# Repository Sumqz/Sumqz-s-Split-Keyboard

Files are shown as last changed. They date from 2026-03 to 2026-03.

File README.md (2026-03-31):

# Sumqz-s-Split-Keyboard

## NOTE TO REVIEWER FROM BLUEPRINT: Because the projects exceeds the 100 dollar price limit of T3 projects i am willing to pay the additional 50 dollars needed. I am happy with a partial grant!

Hey everyone, this is my split keyboard project.

I always felt that traditional keyboards were functional but boring, so I decided to build my own. It can work as two separate halves or snap together with magnets to become a full 75% style keyboard in seconds.

It is hot-swappable, uses nRF52840 boards, and is designed to be easy to build at home.

I sanity-checked this design with my friend before finalizing it.

## Short Description

A DIY wireless split keyboard with magnetic attachment and hot-swap sockets.

## Pictures

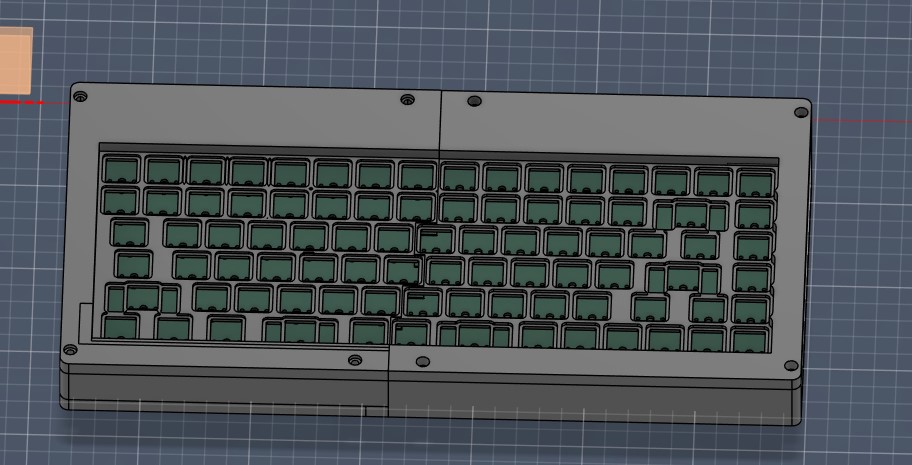
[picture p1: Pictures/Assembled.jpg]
Assembled

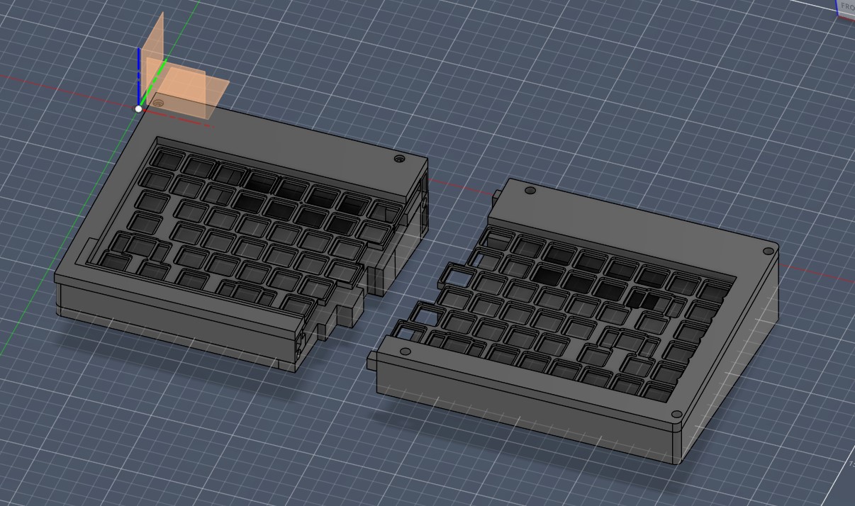
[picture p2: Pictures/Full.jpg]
Full

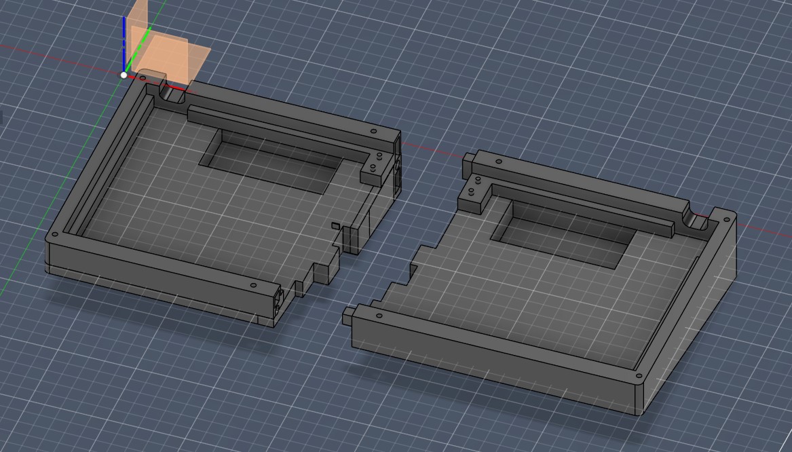
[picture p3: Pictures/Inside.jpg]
Inside

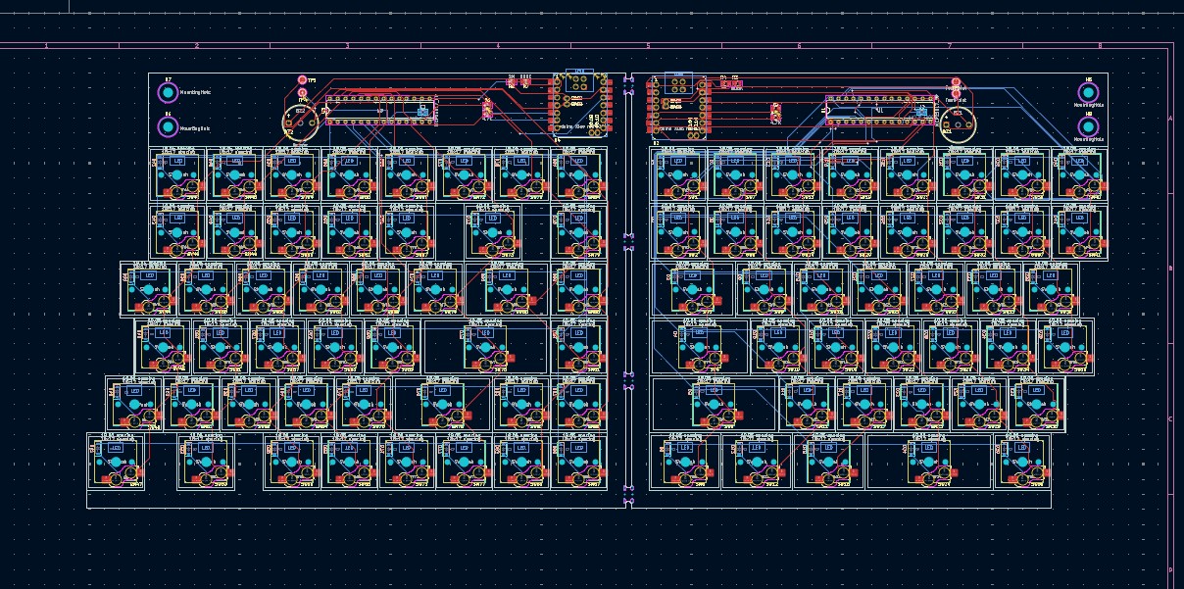
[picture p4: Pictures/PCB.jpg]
PCB

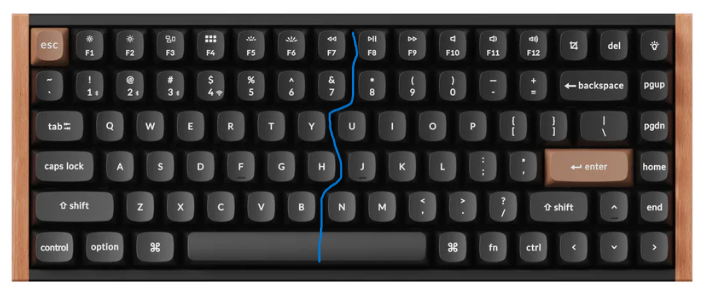
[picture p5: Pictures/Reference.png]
Reference

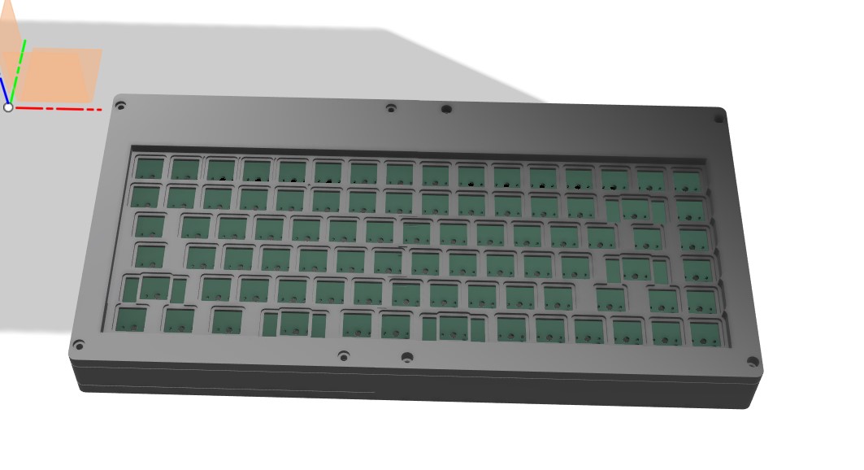
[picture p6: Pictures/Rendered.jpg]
Rendered

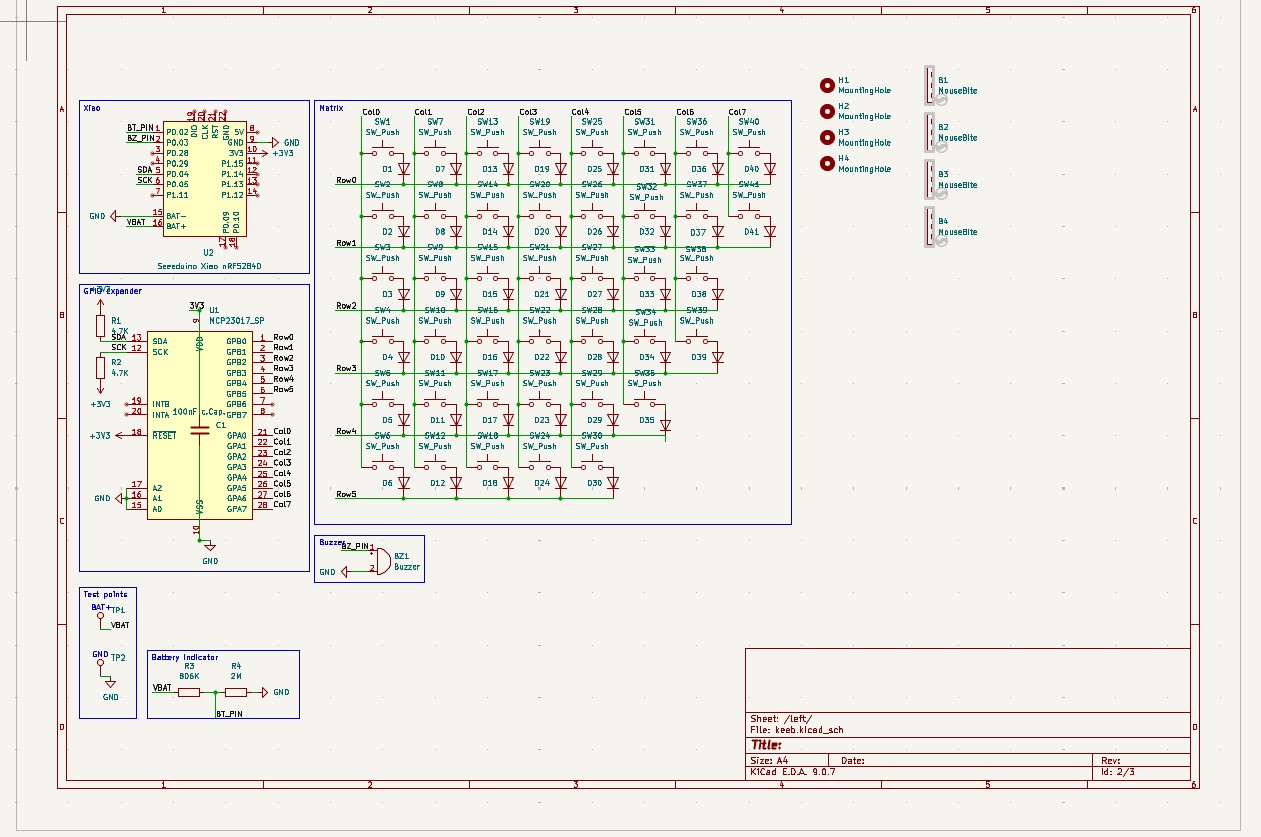
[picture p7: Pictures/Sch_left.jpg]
Schematic Left

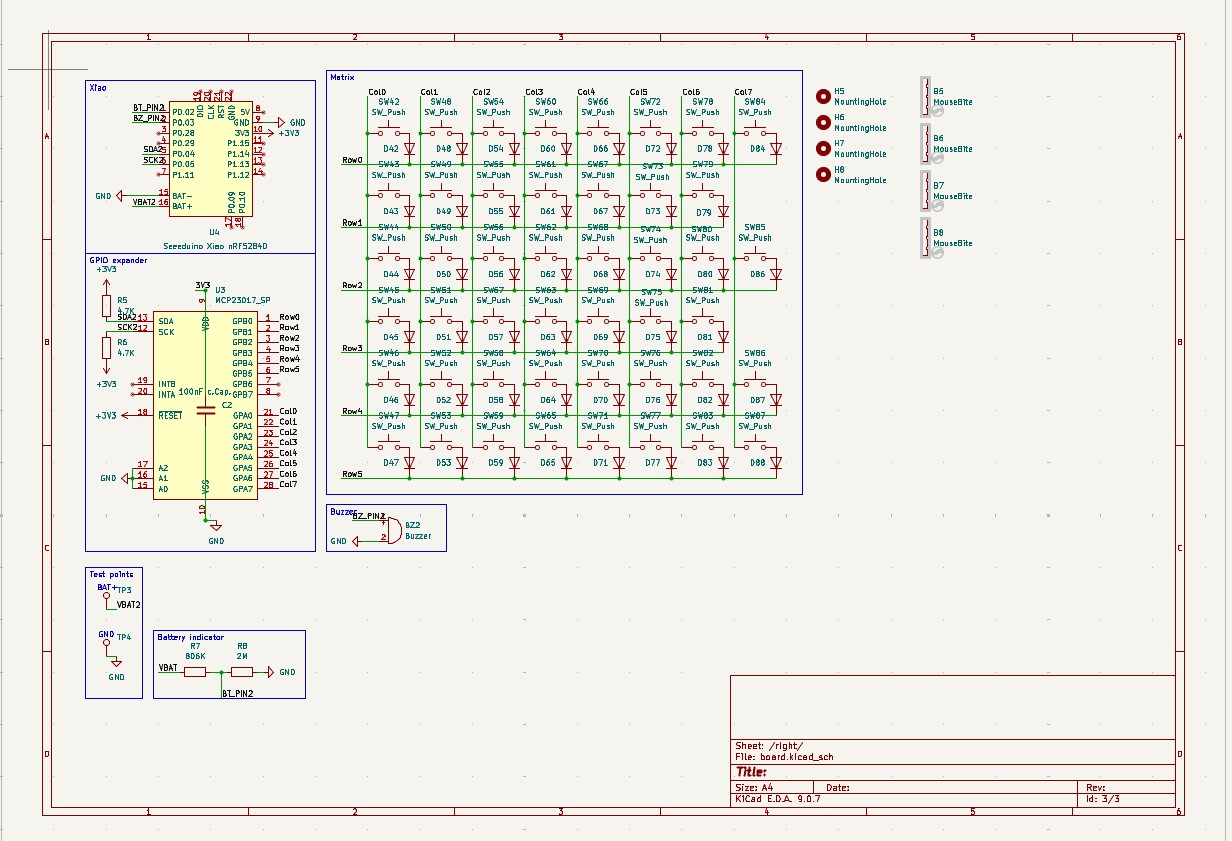
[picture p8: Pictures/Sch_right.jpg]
Schematic Right

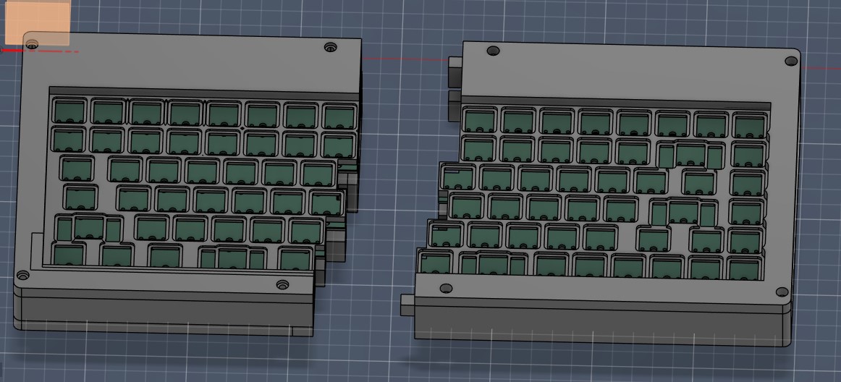
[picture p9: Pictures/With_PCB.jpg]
With PCB

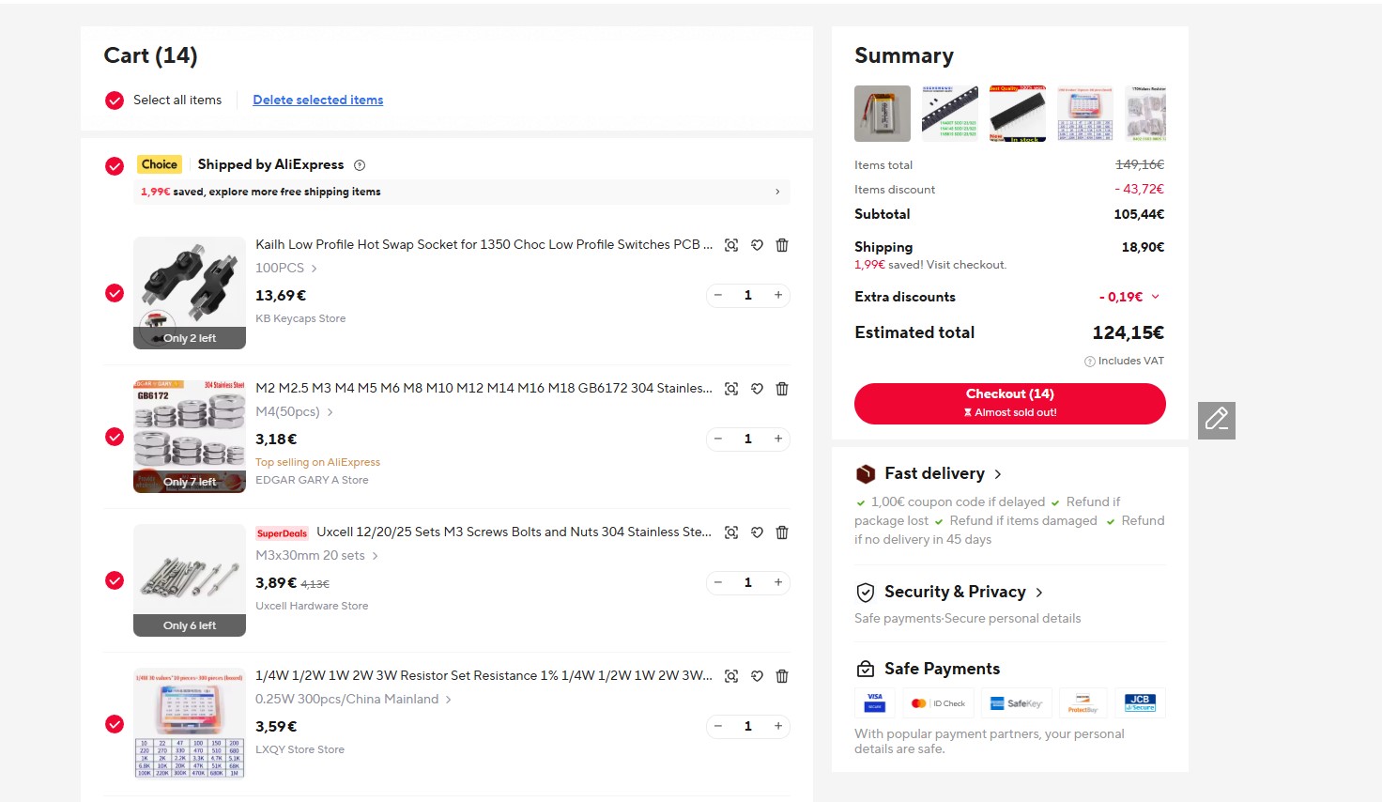
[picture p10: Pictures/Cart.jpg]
Cart

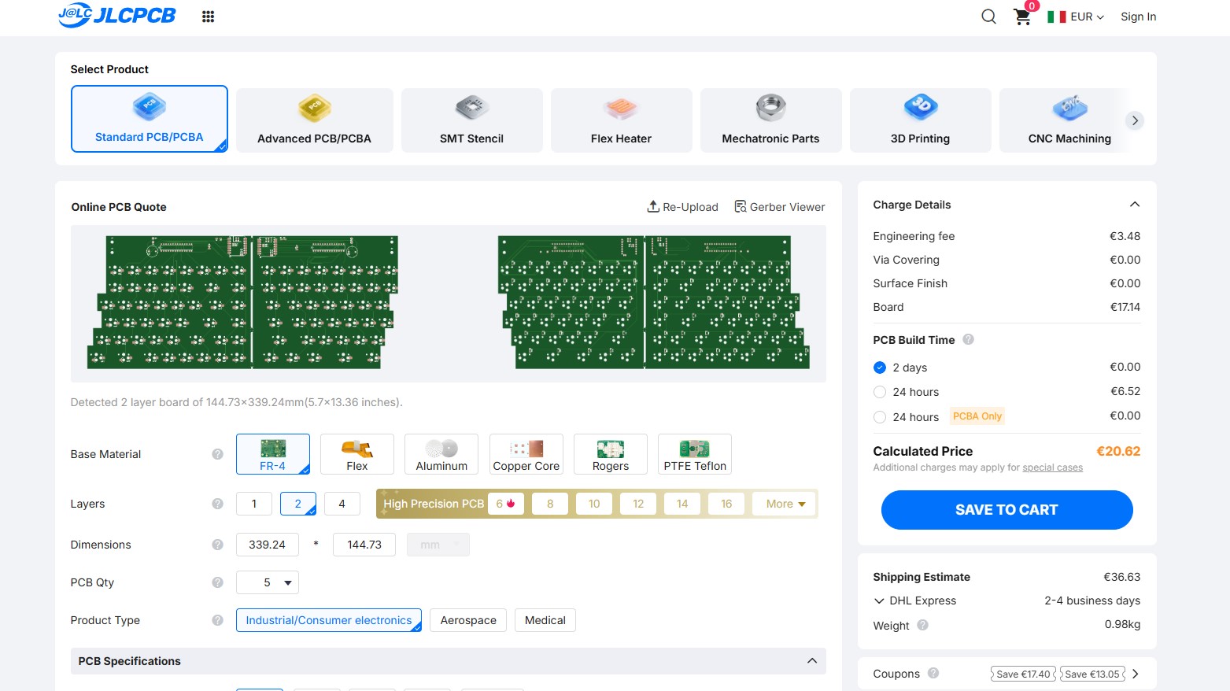
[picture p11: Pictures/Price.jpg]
Price


## Bill of Materials

| Part | Qty | Notes | Link |
|---|---:|---|---|
| nRF52840 (XIAO nRF52840) | 2 | One per side | [Buy](https://it.aliexpress.com/item/1005006988954136.html) |
| MCP23017 GPIO Expander | 2 | MCP23017_SP, DIP-28 package required | [Buy](https://it.aliexpress.com/item/1005009603989894.html) |
| LiPo 1200mAh | 2 | One per side | [Buy](https://it.aliexpress.com/item/1005011550469394.html) |
| Buzzer 12x9.5 / RM7.6 | 2 | Match PCB footprint pin spacing | [Buy](https://it.aliexpress.com/item/1005002576043967.html) |
| Switches (Holy Panda) | 87 | Total keys | [Buy](https://it.aliexpress.com/item/1005004388563696.html) |
| Keycaps (generic) | 87 | Match your layout | [Buy](https://it.aliexpress.com/item/1005011879391386.html) |
| Diodes 1N4148W (SOD-123) | 87 | One per switch | [Buy](https://it.aliexpress.com/item/1005003194674618.html) |
| Resistor 4.7k (0805) | 4 | R1, R2, R5, R6 | [Buy](https://it.aliexpress.com/item/1005011649990763.html) |
| Resistor 806k (0805) | 2 | R3, R7 | [Buy](https://it.aliexpress.com/item/1005011649990763.html) |
| Resistor 2M (0805) | 2 | R4, R8 | [Buy](https://it.aliexpress.com/item/1005011649990763.html) |
| Magnets 6x2 | 8 | 2 per hole | [Buy](https://it.aliexpress.com/item/1005009677185619.html) |
| M3 screw + nut | 4 | 40 mm | [Buy](https://it.aliexpress.com/item/1005008625463950.html) |
| M4 screw | 4 | 50 mm | [Buy](https://it.aliexpress.com/item/1005008625463950.html) |
| M4 nut | 4 | M4 | [Buy](https://it.aliexpress.com/item/1005010329406193.html) |
| Hotswap sockets | 87 | choc | [But](https://it.aliexpress.com/item/1005008543325730.html)

# Total price: about 150 euros or 167 dollars

PCB and case are not included because they are custom-made.

Resistor note: it is usually cheaper to buy one full 0805 resistor assortment than to buy each value separately.

## How to Use

Flash the `.ino` firmware to both nRF52840 boards. Then connect each half to your PC and test that every key works.

You can use it as a split keyboard, or snap both halves together with magnets to use it like a full 75% style board.

## Firmware

Firmware source: `Firmware/SplitKeyboard/SplitKeyboard.ino`

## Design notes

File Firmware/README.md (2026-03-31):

# SplitKeyboard Firmware

This firmware targets your netlist design:
- MCU: Seeed XIAO nRF52840
- Matrix expander: MCP23017 at `0x20`
- Matrix wiring: `GPA0..7 = Col0..7`, `GPB0..5 = Row0..5`
- Battery sense: `BT_PIN (P0.02 / A0)` with divider `806k/2M`

## Build UF2 (both halves)

From repository root:

```powershell
.\Firmware\build-uf2.ps1
```

Output UF2 files are copied to:
- `Production\UF2\SplitKeyboard-left.uf2`
- `Production\UF2\SplitKeyboard-right.uf2`

## Flash

1. Double-press reset on the XIAO board (UF2 drive appears).
2. Copy the matching UF2:
   - Left board: `SplitKeyboard-left.uf2`
   - Right board: `SplitKeyboard-right.uf2`

## Battery Percentage

Battery status is printed every 30 seconds on USB serial at `115200`:

```text
Battery: 84% (3.98V)
```

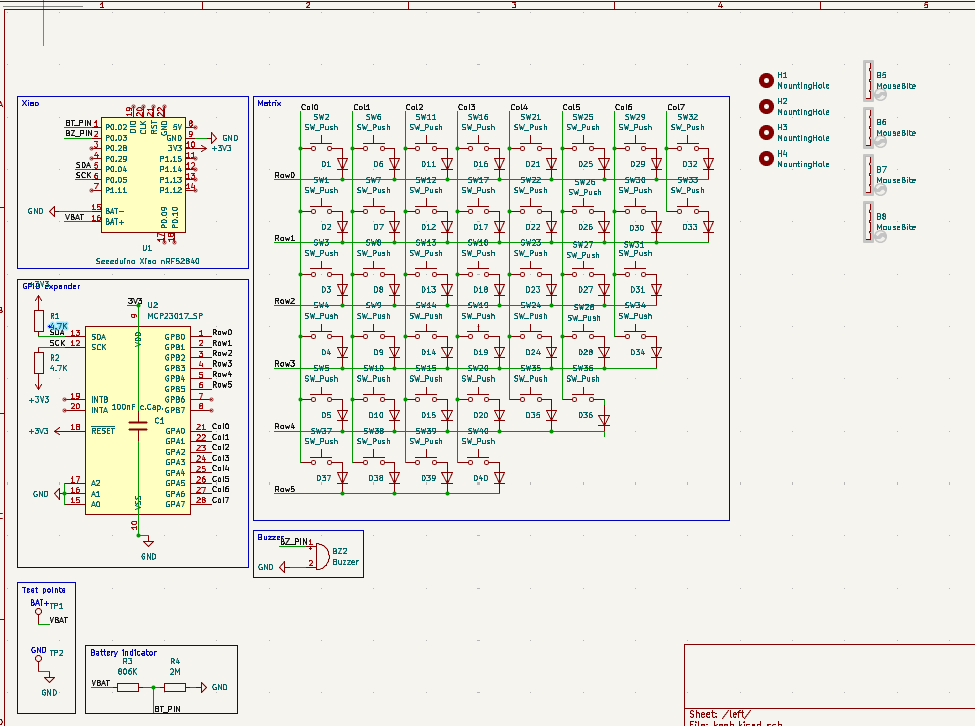
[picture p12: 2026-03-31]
PCB/SplitKeyboard/pics/sch_left.png

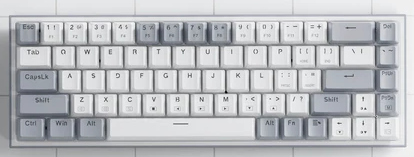
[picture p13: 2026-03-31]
PCB/SplitKeyboard/pics/Split_layout.png

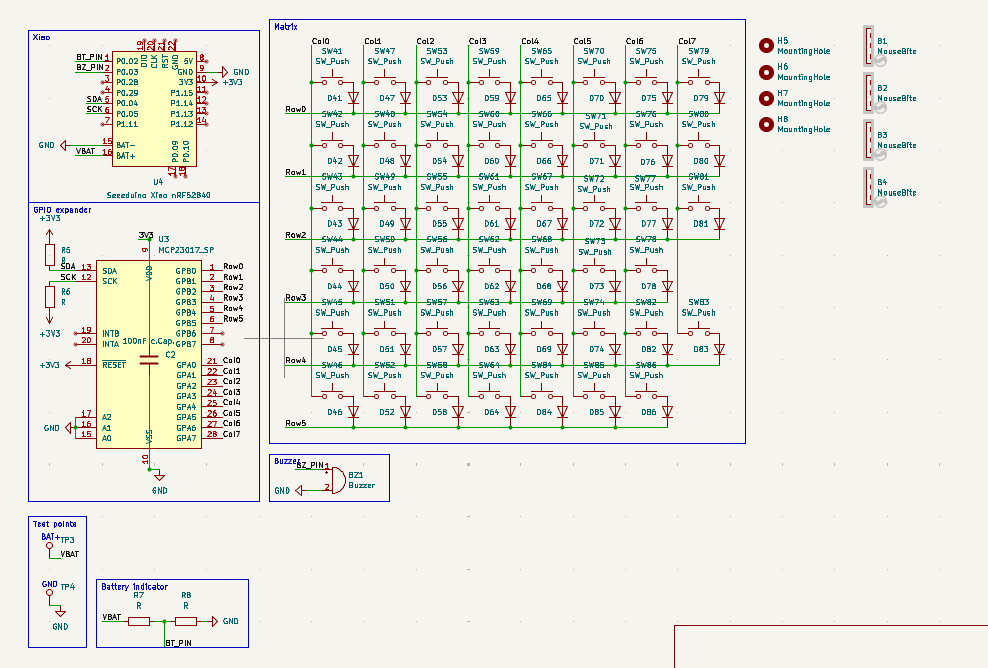
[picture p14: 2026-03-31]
PCB/SplitKeyboard/pics/sch_right.png

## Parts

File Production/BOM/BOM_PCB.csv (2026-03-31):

Id | Designator | Footprint | Quantity | Designation | Supplier and ref
1 | SW55,SW72,SW54,SW42,SW17,SW48,SW59,SW9,SW22,SW23,SW68,SW8,SW10,SW87,SW67,SW57,SW30,SW34,SW37,SW36,SW32,SW86,SW38,SW58,SW82,SW78,SW84,SW46,SW11,SW65,SW79,SW2,SW71,SW31,SW52,SW39,SW26,SW41,SW28,SW45,SW51,SW70,SW85,SW33,SW66,SW44,SW74,SW7,SW21,SW27,SW40,SW14,SW25,SW64,SW47,SW60,SW61,SW62,SW29,SW16,SW73,SW50,SW63,SW20,SW43,SW69,SW1,SW83,SW81,SW19,SW35,SW13,SW49,SW53,SW15,SW56,SW77 | SW_choc_v1_HS_CPG135001S30_1u | 77 | SW_Push
2 | R5,R6,R2,R1 | R_0805_2012Metric | 4 | 4.7K
3 | TP4,TP2,TP1,TP2,TP3 | TestPoint_Pad_D2.0mm | 5 | TestPoint
4 | U1,U3 | DIP-28_W7.62mm | 2 | MCP23017_SP
5 | BZ2,BZ1 | Buzzer_12x9.5RM7.6 | 2 | Buzzer
6 | SW4,SW76 | SW_choc_v1_HS_CPG135001S30_1.75u | 2 | SW_Push
7 | SW5,SW75,SW24 | SW_choc_v1_HS_CPG135001S30_2.25u | 3 | SW_Push
8 | R8,R4 | R_0805_2012Metric | 2 | 2M
9 | SW18,SW12,SW6 | SW_choc_v1_HS_CPG135001S30_1.25u | 3 | SW_Push
10 | SW80,SW3 | SW_choc_v1_HS_CPG135001S30_1.5u | 2 | SW_Push
11 | R7,R3 | R_0805_2012Metric | 2 | 806K
12 | D10,D44,D16,D22,D39,D38,D25,D5,D56,D46,D32,D49,D79,D71,D9,D6,D78,D55,D59,D8,D42,D68,D47,D18,D37,D36,D17,D4,D53,D64,D61,D88,D40,D60,D72,D27,D19,D45,D57,D12,D50,D58,D41,D2,D65,D67,D3,D48,D83,D24,D51,D74,D26,D81,D13,D69,D77,D23,D52,D15,D43,D75,D86,D66,D33,D1,D7,D84,D63,D31,D30,D11,D29,D87,D70,D20,D73,D21,D82,D34,D28,D76,D80,D62,D54,D35,D14 | D_SOD-123 | 87 | D
13 | C2,C1 | C_0805_2012Metric | 2 | 100nF c.Cap.

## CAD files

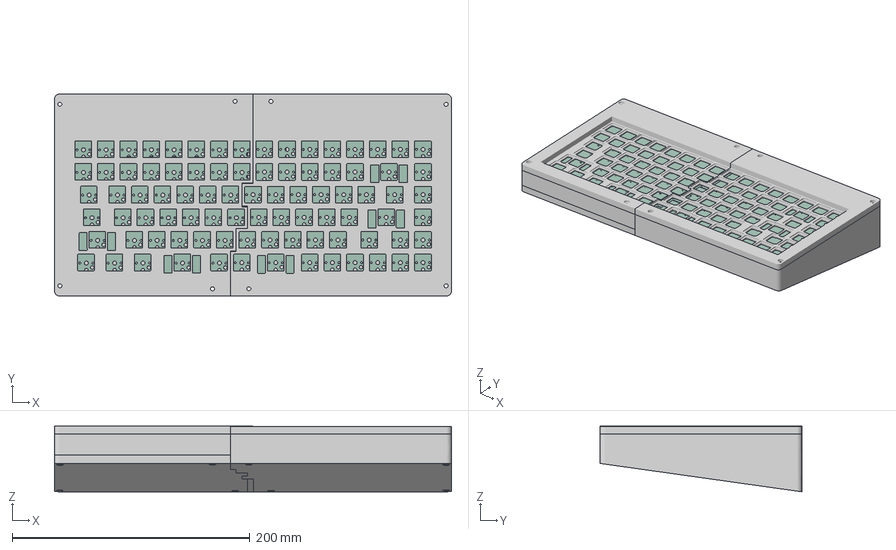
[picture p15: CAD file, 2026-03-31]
CAD/Split Keyboard.3mf
333.8 x 169.7 x 55.2 mm

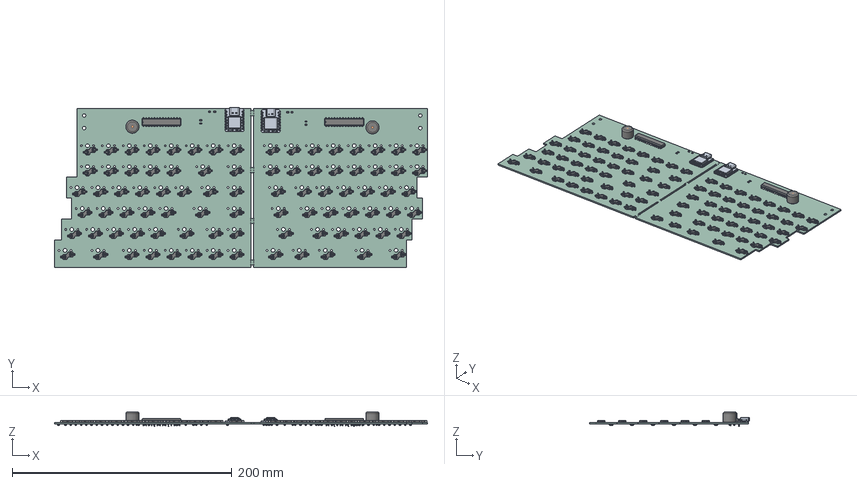
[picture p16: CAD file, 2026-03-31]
CAD/PCB.step
339.2 x 145.5 x 12.8 mm
pin x 174
socket x 87
R_0805_2012Metric x 8
DIP-28_W7.62mm x 2
Buzzer_12x9.5RM7.6 x 2
PCB 1.19.1 x 2
D_SOD-123 x 87
C_0805_2012Metric x 2
SplitKeyboard_PCB

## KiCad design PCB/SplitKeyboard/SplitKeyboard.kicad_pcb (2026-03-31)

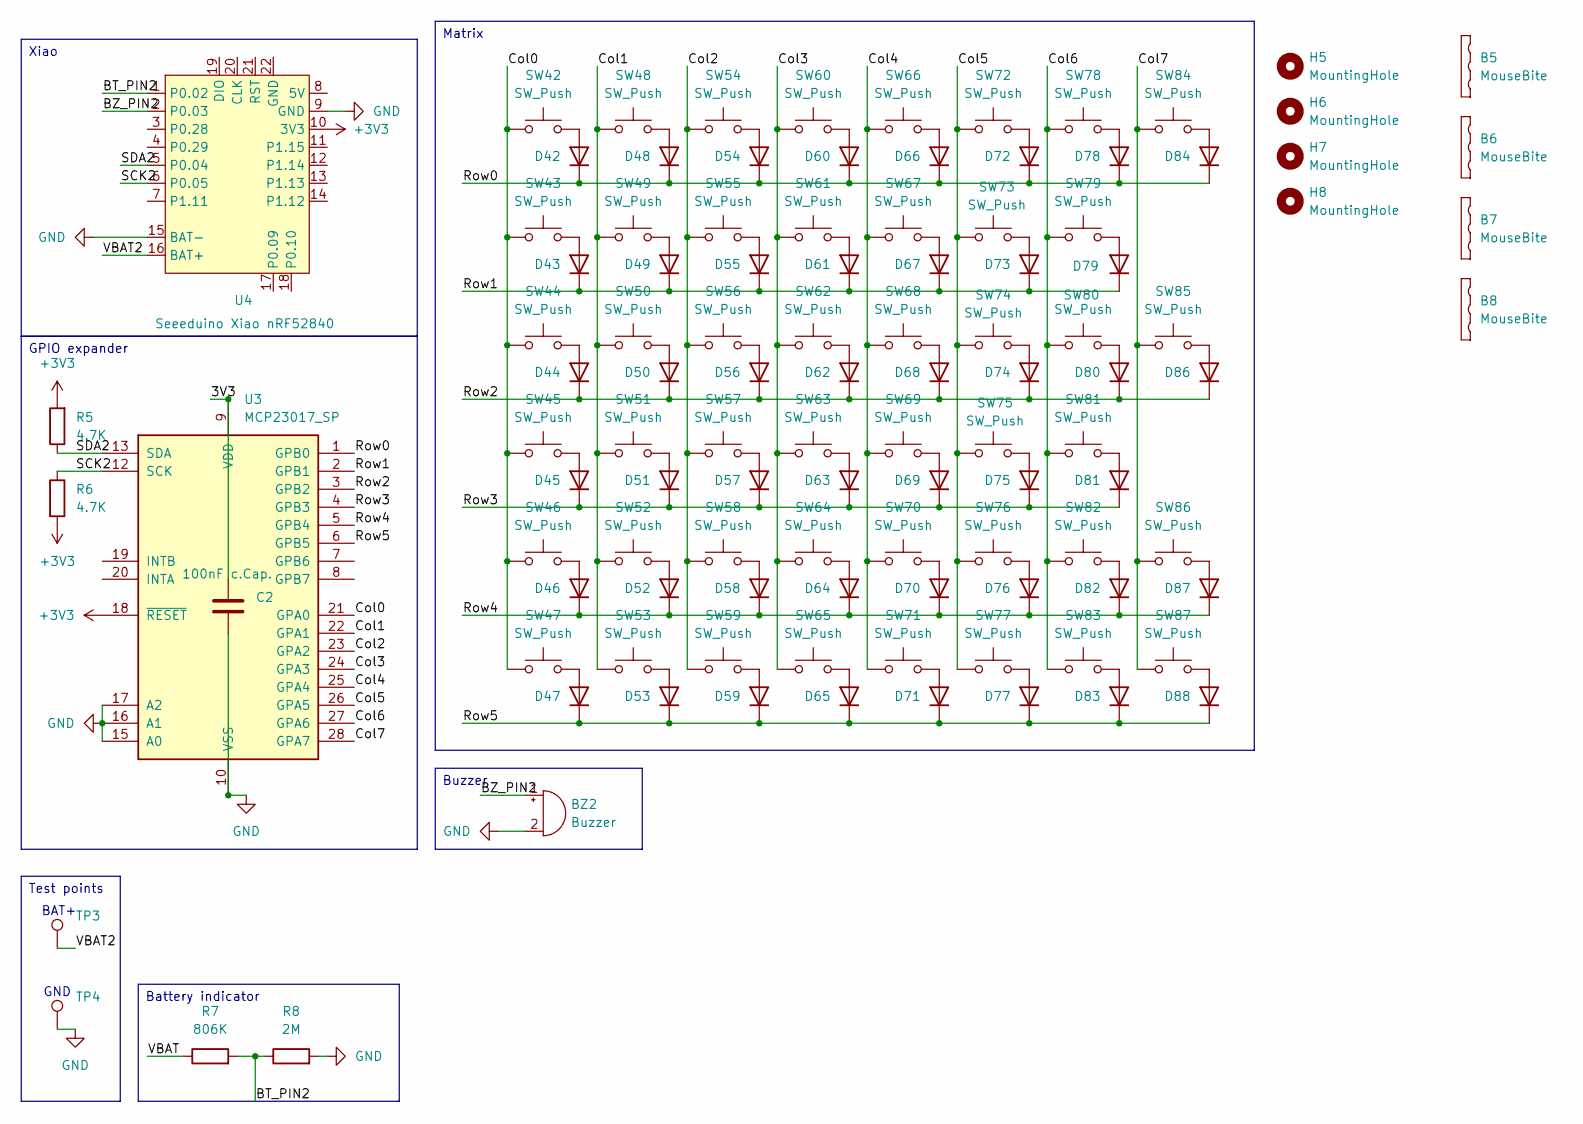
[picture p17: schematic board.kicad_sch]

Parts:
B5, B6, B7, B8: MouseBite; MouseBite-Slot_2.0x4.5mm_inset_D0.5mm_P0.85mm_5h_Trace
BZ2: Buzzer; Buzzer_12x9.5RM7.6
C2: 100nF c.Cap.; C_0805_2012Metric
D42, D43, D44, D45, D46, D47, D48, D49, D50, D51, D52, D53, D54, D55, D56, D57, D58, D59, D60, D61, D62, D63, D64, D65, D66, D67, D68, D69, D70, D71, D72, D73, D74, D75, D76, D77, D78, D79, D80, D81, D82, D83, D84, D86, D87, D88: D; D_SOD-123
H5, H6, H7, H8: MountingHole; MountingHole_3.2mm_M3
R5, R6: 4.7K; R_0805_2012Metric
R7: 806K; R_0805_2012Metric
R8: 2M; R_0805_2012Metric
SW42, SW43, SW44, SW45, SW46, SW47, SW48, SW49, SW50, SW51, SW52, SW53, SW54, SW55, SW56, SW57, SW58, SW59, SW60, SW61, SW62, SW63, SW64, SW65, SW66, SW67, SW68, SW69, SW70, SW71, SW72, SW73, SW74, SW77, SW78, SW79, SW81, SW82, SW83, SW84, SW85, SW86, SW87: SW_Push; SW_choc_v1_HS_CPG135001S30_1u
SW75: SW_Push; SW_choc_v1_HS_CPG135001S30_2.25u
SW76: SW_Push; SW_choc_v1_HS_CPG135001S30_1.75u
SW80: SW_Push; SW_choc_v1_HS_CPG135001S30_1.5u
TP3, TP4: TestPoint; TestPoint_Pad_D2.0mm
U3: MCP23017_SP; DIP-28_W7.62mm
U4: Seeeduino Xiao nRF52840; Xiao_nRF52840_ACH

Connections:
+3V3: R5.2, R6.2, U3.18 (~RESET), U4.10 (3V3); also elsewhere on the board
/right/3V3: C2.1, U3.9 (VDD)
/right/BT_PIN2: R7.2, R8.1, U4.1 (P0.02)
/right/BZ_PIN2: BZ2.1 (+), U4.2 (P0.03)
/right/Col0: SW42.1, SW43.1, SW44.1, SW45.1, SW46.1, SW47.1, U3.21 (GPA0)
/right/Col1: SW48.1, SW49.1, SW50.1, SW51.1, SW52.1, SW53.1, U3.22 (GPA1)
/right/Col2: SW54.1, SW55.1, SW56.1, SW57.1, SW58.1, SW59.1, U3.23 (GPA2)
/right/Col3: SW60.1, SW61.1, SW62.1, SW63.1, SW64.1, SW65.1, U3.24 (GPA3)
/right/Col4: SW66.1, SW67.1, SW68.1, SW69.1, SW70.1, SW71.1, U3.25 (GPA4)
/right/Col5: SW72.1, SW73.1, SW74.1, SW75.1, SW76.1, SW77.1, U3.26 (GPA5)
/right/Col6: SW78.1, SW79.1, SW80.1, SW81.1, SW82.1, SW83.1, U3.27 (GPA6)
/right/Col7: SW84.1, SW85.1, SW86.1, SW87.1, U3.28 (GPA7)
/right/Row0: D42.1 (K), D48.1 (K), D54.1 (K), D60.1 (K), D66.1 (K), D72.1 (K), D78.1 (K), D84.1 (K), U3.1 (GPB0)
/right/Row1: D43.1 (K), D49.1 (K), D55.1 (K), D61.1 (K), D67.1 (K), D73.1 (K), D79.1 (K), U3.2 (GPB1)
/right/Row2: D44.1 (K), D50.1 (K), D56.1 (K), D62.1 (K), D68.1 (K), D74.1 (K), D80.1 (K), D86.1 (K), U3.3 (GPB2)
/right/Row3: D45.1 (K), D51.1 (K), D57.1 (K), D63.1 (K), D69.1 (K), D75.1 (K), D81.1 (K), U3.4 (GPB3)
/right/Row4: D46.1 (K), D52.1 (K), D58.1 (K), D64.1 (K), D70.1 (K), D76.1 (K), D82.1 (K), D87.1 (K), U3.5 (GPB4)
/right/Row5: D47.1 (K), D53.1 (K), D59.1 (K), D65.1 (K), D71.1 (K), D77.1 (K), D83.1 (K), D88.1 (K), U3.6 (GPB5)
/right/SCK2: R6.1, U3.12 (SCK), U4.6 (P0.05)
/right/SDA2: R5.1, U3.13 (SDA), U4.5 (P0.04)
/right/VBAT: R7.1
/right/VBAT2: TP3.1, U4.16 (BAT+)
GND: BZ2.2 (-), C2.2, R8.2, TP4.1, U3.10 (VSS), U3.15 (A0), U3.16 (A1), U3.17 (A2), U4.9 (GND), U4.15 (BAT-); also elsewhere on the board
unnamed: D42.2 (A), SW42.2
unnamed: D43.2 (A), SW43.2
unnamed: D44.2 (A), SW44.2
unnamed: D45.2 (A), SW45.2
unnamed: D46.2 (A), SW46.2
unnamed: D47.2 (A), SW47.2
unnamed: D48.2 (A), SW48.2
unnamed: D49.2 (A), SW49.2
unnamed: D50.2 (A), SW50.2
unnamed: D51.2 (A), SW51.2
unnamed: D52.2 (A), SW52.2
unnamed: D53.2 (A), SW53.2
unnamed: D54.2 (A), SW54.2
unnamed: D55.2 (A), SW55.2
unnamed: D56.2 (A), SW56.2
unnamed: D57.2 (A), SW57.2
unnamed: D58.2 (A), SW58.2
unnamed: D59.2 (A), SW59.2
unnamed: D60.2 (A), SW60.2
unnamed: D61.2 (A), SW61.2
unnamed: D62.2 (A), SW62.2
unnamed: D63.2 (A), SW63.2
unnamed: D64.2 (A), SW64.2
unnamed: D65.2 (A), SW65.2
unnamed: D66.2 (A), SW66.2
unnamed: D67.2 (A), SW67.2
unnamed: D68.2 (A), SW68.2
unnamed: D69.2 (A), SW69.2
unnamed: D70.2 (A), SW70.2
unnamed: D71.2 (A), SW71.2
unnamed: D72.2 (A), SW72.2
unnamed: D73.2 (A), SW73.2
unnamed: D74.2 (A), SW74.2
unnamed: D75.2 (A), SW75.2
unnamed: D76.2 (A), SW76.2
unnamed: D77.2 (A), SW77.2
unnamed: D78.2 (A), SW78.2
unnamed: D79.2 (A), SW79.2
unnamed: D80.2 (A), SW80.2
unnamed: D81.2 (A), SW81.2
unnamed: D82.2 (A), SW82.2
unnamed: D83.2 (A), SW83.2
unnamed: D84.2 (A), SW84.2
unnamed: D86.2 (A), SW85.2
unnamed: D87.2 (A), SW86.2
unnamed: D88.2 (A), SW87.2

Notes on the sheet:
BAT+
GND
GPIO expander
Xiao
Test points
Buzzer
Battery indicator
Matrix

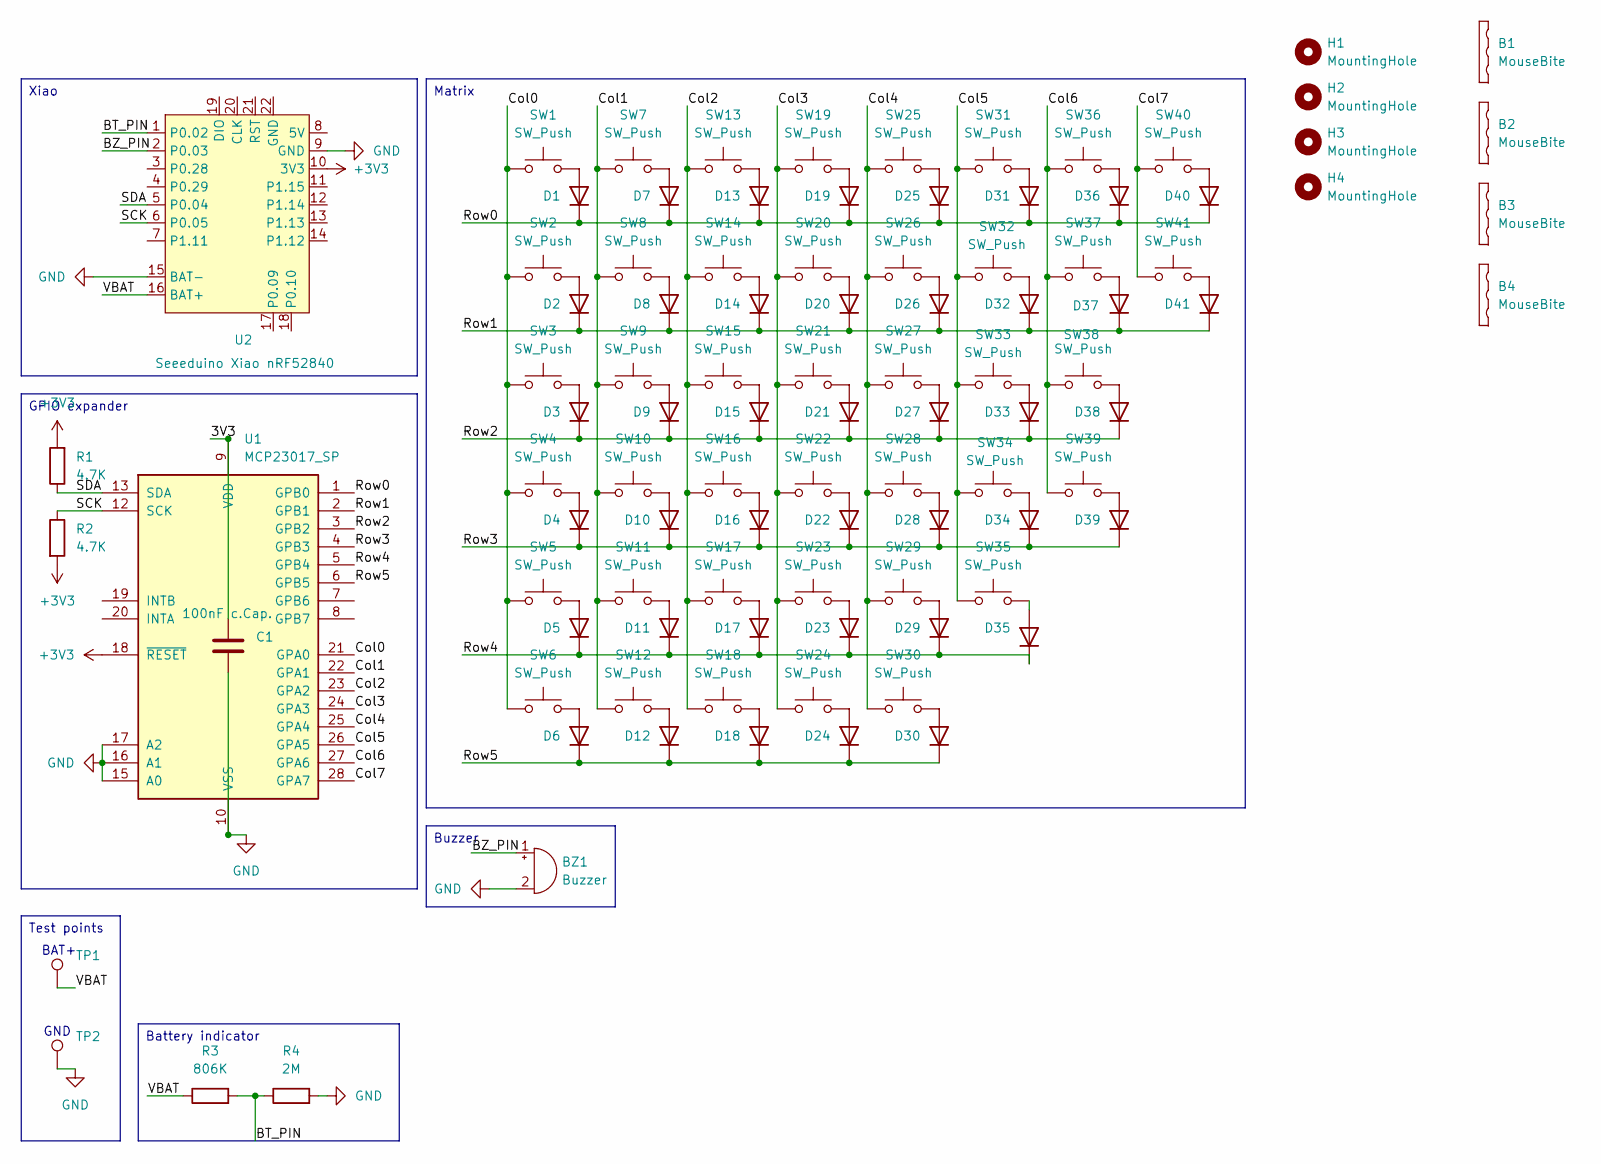
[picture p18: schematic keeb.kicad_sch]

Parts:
B1, B2, B3, B4: MouseBite; MouseBite-Slot_2.0x4.5mm_inset_D0.5mm_P0.85mm_5h_Trace
BZ1: Buzzer; Buzzer_12x9.5RM7.6
C1: 100nF c.Cap.; C_0805_2012Metric
D1, D2, D3, D4, D5, D6, D7, D8, D9, D10, D11, D12, D13, D14, D15, D16, D17, D18, D19, D20, D21, D22, D23, D24, D25, D26, D27, D28, D29, D30, D31, D32, D33, D34, D35, D36, D37, D38, D39, D40, D41: D; D_SOD-123
H1, H2, H3, H4: MountingHole; MountingHole_3.2mm_M3
R1, R2: 4.7K; R_0805_2012Metric
R3: 806K; R_0805_2012Metric
R4: 2M; R_0805_2012Metric
SW1, SW2, SW7, SW8, SW9, SW10, SW11, SW13, SW14, SW15, SW16, SW17, SW19, SW20, SW21, SW22, SW23, SW25, SW26, SW27, SW28, SW29, SW30, SW31, SW32, SW33, SW34, SW35, SW36, SW37, SW38, SW39, SW40, SW41: SW_Push; SW_choc_v1_HS_CPG135001S30_1u
SW3: SW_Push; SW_choc_v1_HS_CPG135001S30_1.5u
SW4: SW_Push; SW_choc_v1_HS_CPG135001S30_1.75u
SW5, SW24: SW_Push; SW_choc_v1_HS_CPG135001S30_2.25u
SW6, SW12, SW18: SW_Push; SW_choc_v1_HS_CPG135001S30_1.25u
TP1, TP2: TestPoint; TestPoint_Pad_D2.0mm
U1: MCP23017_SP; DIP-28_W7.62mm
U2: Seeeduino Xiao nRF52840; Xiao_nRF52840_ACH

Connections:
+3V3: R1.2, R2.2, U1.18 (~RESET), U2.10 (3V3); also elsewhere on the board
/left/3V3: C1.1, U1.9 (VDD)
/left/BT_PIN: R3.2, R4.1, U2.1 (P0.02)
/left/BZ_PIN: BZ1.1 (+), U2.2 (P0.03)
/left/Col0: SW1.1, SW2.1, SW3.1, SW4.1, SW5.1, SW6.1, U1.21 (GPA0)
/left/Col1: SW7.1, SW8.1, SW9.1, SW10.1, SW11.1, SW12.1, U1.22 (GPA1)
/left/Col2: SW13.1, SW14.1, SW15.1, SW16.1, SW17.1, SW18.1, U1.23 (GPA2)
/left/Col3: SW19.1, SW20.1, SW21.1, SW22.1, SW23.1, SW24.1, U1.24 (GPA3)
/left/Col4: SW25.1, SW26.1, SW27.1, SW28.1, SW29.1, SW30.1, U1.25 (GPA4)
/left/Col5: SW31.1, SW32.1, SW33.1, SW34.1, SW35.1, U1.26 (GPA5)
/left/Col6: SW36.1, SW37.1, SW38.1, SW39.1, U1.27 (GPA6)
/left/Col7: SW40.1, SW41.1, U1.28 (GPA7)
/left/Row0: D1.1 (K), D7.1 (K), D13.1 (K), D19.1 (K), D25.1 (K), D31.1 (K), D36.1 (K), D40.1 (K), U1.1 (GPB0)
/left/Row1: D2.1 (K), D8.1 (K), D14.1 (K), D20.1 (K), D26.1 (K), D32.1 (K), D37.1 (K), D41.1 (K), U1.2 (GPB1)
/left/Row2: D3.1 (K), D9.1 (K), D15.1 (K), D21.1 (K), D27.1 (K), D33.1 (K), D38.1 (K), U1.3 (GPB2)
/left/Row3: D4.1 (K), D10.1 (K), D16.1 (K), D22.1 (K), D28.1 (K), D34.1 (K), D39.1 (K), U1.4 (GPB3)
/left/Row4: D5.1 (K), D11.1 (K), D17.1 (K), D23.1 (K), D29.1 (K), D35.1 (K), U1.5 (GPB4)
/left/Row5: D6.1 (K), D12.1 (K), D18.1 (K), D24.1 (K), D30.1 (K), U1.6 (GPB5)
/left/SCK: R2.1, U1.12 (SCK), U2.6 (P0.05)
/left/SDA: R1.1, U1.13 (SDA), U2.5 (P0.04)
/left/VBAT: R3.1, TP1.1, U2.16 (BAT+)
GND: BZ1.2 (-), C1.2, R4.2, TP2.1, U1.10 (VSS), U1.15 (A0), U1.16 (A1), U1.17 (A2), U2.9 (GND), U2.15 (BAT-); also elsewhere on the board
unnamed: D1.2 (A), SW1.2
unnamed: D2.2 (A), SW2.2
unnamed: D3.2 (A), SW3.2
unnamed: D4.2 (A), SW4.2
unnamed: D5.2 (A), SW5.2
unnamed: D6.2 (A), SW6.2
unnamed: D7.2 (A), SW7.2
unnamed: D8.2 (A), SW8.2
unnamed: D9.2 (A), SW9.2
unnamed: D10.2 (A), SW10.2
unnamed: D11.2 (A), SW11.2
unnamed: D12.2 (A), SW12.2
unnamed: D13.2 (A), SW13.2
unnamed: D14.2 (A), SW14.2
unnamed: D15.2 (A), SW15.2
unnamed: D16.2 (A), SW16.2
unnamed: D17.2 (A), SW17.2
unnamed: D18.2 (A), SW18.2
unnamed: D19.2 (A), SW19.2
unnamed: D20.2 (A), SW20.2
unnamed: D21.2 (A), SW21.2
unnamed: D22.2 (A), SW22.2
unnamed: D23.2 (A), SW23.2
unnamed: D24.2 (A), SW24.2
unnamed: D25.2 (A), SW25.2
unnamed: D26.2 (A), SW26.2
unnamed: D27.2 (A), SW27.2
unnamed: D28.2 (A), SW28.2
unnamed: D29.2 (A), SW29.2
unnamed: D30.2 (A), SW30.2
unnamed: D31.2 (A), SW31.2
unnamed: D32.2 (A), SW32.2
unnamed: D33.2 (A), SW33.2
unnamed: D34.2 (A), SW34.2
unnamed: D35.2 (A), SW35.2
unnamed: D36.2 (A), SW36.2
unnamed: D37.2 (A), SW37.2
unnamed: D38.2 (A), SW38.2
unnamed: D39.2 (A), SW39.2
unnamed: D40.2 (A), SW40.2
unnamed: D41.2 (A), SW41.2

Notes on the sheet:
GND
BAT+
Battery indicator
Buzzer
Matrix
GPIO expander
Xiao
Test points

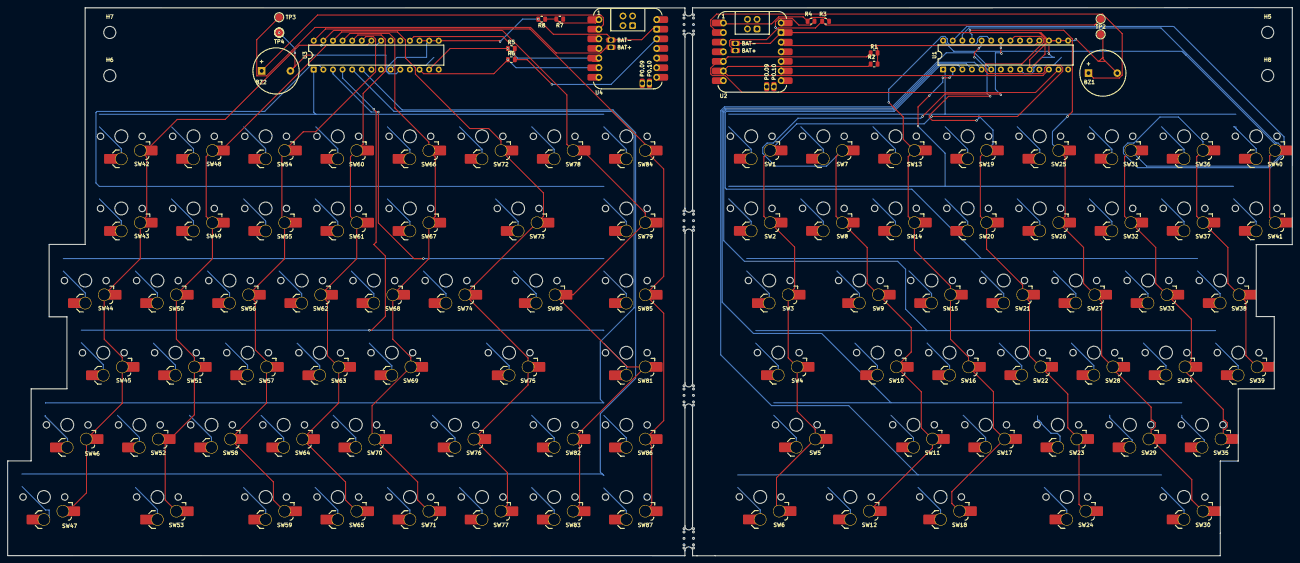
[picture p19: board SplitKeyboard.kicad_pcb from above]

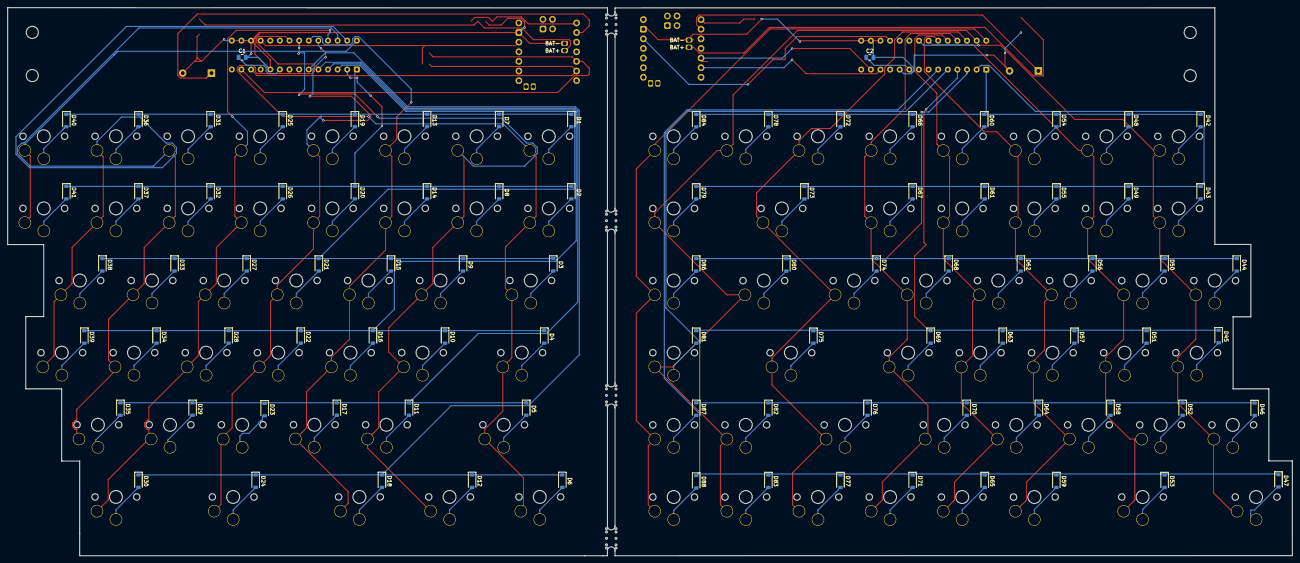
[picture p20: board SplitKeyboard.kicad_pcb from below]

Board: 2 copper layers, 339.2 x 144.7 mm, 203 parts (89 on the bottom side), 129 nets.

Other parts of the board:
TP2#2: TestPoint; TestPoint_Pad_D2.0mm

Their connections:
GND: TP2#2.1; also elsewhere on the board

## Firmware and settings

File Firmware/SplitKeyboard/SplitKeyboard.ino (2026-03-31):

#include <Arduino.h>
#include <Wire.h>
#include <Adafruit_MCP23X17.h>
#include <PluggableUSBHID.h>
#include <USBKeyboard.h>

#if !defined(HALF_LEFT) && !defined(HALF_RIGHT)
#define HALF_LEFT
#endif

namespace {
constexpr uint8_t kRows = 6;
constexpr uint8_t kCols = 8;
constexpr uint8_t kMcpAddress = 0x20;
constexpr uint8_t kDebounceMs = 5;

constexpr uint8_t kBatterySensePin = A0;
constexpr uint8_t kBuzzerPin = D1;

constexpr float kBatteryDividerScale = (806.0f + 2000.0f) / 2000.0f;
constexpr float kBatteryEmptyV = 3.30f;
constexpr float kBatteryFullV = 4.20f;

constexpr uint8_t H_A = 0x04;
constexpr uint8_t H_B = 0x05;
constexpr uint8_t H_C = 0x06;
constexpr uint8_t H_D = 0x07;
constexpr uint8_t H_E = 0x08;
constexpr uint8_t H_F = 0x09;
constexpr uint8_t H_G = 0x0A;
constexpr uint8_t H_H = 0x0B;
constexpr uint8_t H_I = 0x0C;
constexpr uint8_t H_J = 0x0D;
constexpr uint8_t H_K = 0x0E;
constexpr uint8_t H_L = 0x0F;
constexpr uint8_t H_M = 0x10;
constexpr uint8_t H_N = 0x11;
constexpr uint8_t H_O = 0x12;
constexpr uint8_t H_P = 0x13;
constexpr uint8_t H_Q = 0x14;
constexpr uint8_t H_R = 0x15;
constexpr uint8_t H_S = 0x16;
constexpr uint8_t H_T = 0x17;
constexpr uint8_t H_U = 0x18;
constexpr uint8_t H_V = 0x19;
constexpr uint8_t H_W = 0x1A;
constexpr uint8_t H_X = 0x1B;
constexpr uint8_t H_Y = 0x1C;
constexpr uint8_t H_Z = 0x1D;
constexpr uint8_t H_1 = 0x1E;
constexpr uint8_t H_2 = 0x1F;
constexpr uint8_t H_3 = 0x20;
constexpr uint8_t H_4 = 0x21;
constexpr uint8_t H_5 = 0x22;
constexpr uint8_t H_6 = 0x23;
constexpr uint8_t H_7 = 0x24;
constexpr uint8_t H_8 = 0x25;
constexpr uint8_t H_9 = 0x26;
constexpr uint8_t H_0 = 0x27;
constexpr uint8_t H_ENTER = 0x28;
constexpr uint8_t H_ESC = 0x29;
constexpr uint8_t H_BKSP = 0x2A;
constexpr uint8_t H_TAB = 0x2B;
constexpr uint8_t H_SPACE = 0x2C;
constexpr uint8_t H_MINUS = 0x2D;
constexpr uint8_t H_EQUAL = 0x2E;
constexpr uint8_t H_LBKT = 0x2F;
constexpr uint8_t H_RBKT = 0x30;
constexpr uint8_t H_BSLS = 0x31;
constexpr uint8_t H_SCLN = 0x33;
constexpr uint8_t H_QUOT = 0x34;
constexpr uint8_t H_COMM = 0x36;
constexpr uint8_t H_DOT = 0x37;
constexpr uint8_t H_SLSH = 0x38;
constexpr uint8_t H_CAPS = 0x39;
constexpr uint8_t H_F7 = 0x40;
constexpr uint8_t H_F8 = 0x41;
constexpr uint8_t H_F9 = 0x42;
constexpr uint8_t H_F10 = 0x43;
constexpr uint8_t H_F11 = 0x44;
constexpr uint8_t H_F12 = 0x45;
constexpr uint8_t H_INS = 0x49;
constexpr uint8_t H_HOME = 0x4A;
constexpr uint8_t H_PGUP = 0x4B;
constexpr uint8_t H_DEL = 0x4C;
constexpr uint8_t H_END = 0x4D;
constexpr uint8_t H_PGDN = 0x4E;
constexpr uint8_t H_RIGHT = 0x4F;
constexpr uint8_t H_LEFT = 0x50;
constexpr uint8_t H_DOWN = 0x51;
constexpr uint8_t H_UP = 0x52;

struct KeyDef {
  uint8_t usage;
  uint8_t modifier;
};

constexpr KeyDef N = {0, 0};
constexpr KeyDef K(uint8_t usage) { return {usage, 0}; }
constexpr KeyDef M(uint8_t modifier) { return {0, modifier}; }

constexpr uint8_t kColPins[kCols] = {0, 1, 2, 3, 4, 5, 6, 7};
constexpr uint8_t kRowPins[kRows] = {8, 9, 10, 11, 12, 13};

const KeyDef kLeftKeymap[kRows][kCols] = {
  {K(H_ESC), K(H_1), K(H_2), K(H_3), K(H_4), K(H_5), K(H_6), K(H_7)},
  {K(H_TAB), K(H_Q), K(H_W), K(H_E), K(H_R), K(H_T), K(H_Y), K(H_U)},
  {K(H_CAPS), K(H_A), K(H_S), K(H_D), K(H_F), K(H_G), K(H_H), N},
  {M(arduino::KEY_SHIFT), K(H_Z), K(H_X), K(H_C), K(H_V), K(H_B), K(H_N), N},
  {M(arduino::KEY_CTRL), M(arduino::KEY_LOGO), M(arduino::KEY_ALT), K(H_SPACE), K(H_BKSP), K(H_ENTER), N, N},
  {K(H_LEFT), K(H_DOWN), K(H_UP), K(H_RIGHT), K(H_DEL), N, N, N}
};

const KeyDef kRightKeymap[kRows][kCols] = {
  {K(H_8), K(H_9), K(H_0), K(H_MINUS), K(H_EQUAL), K(H_LBKT), K(H_RBKT), K(H_BSLS)},
  {K(H_I), K(H_O), K(H_P), K(H_SCLN), K(H_QUOT), K(H_BKSP), K(H_PGUP), K(H_HOME)},
  {K(H_J), K(H_K), K(H_L), K(H_COMM), K(H_DOT), K(H_SLSH), K(H_ENTER), K(H_END)},
  {K(H_M), K(H_F7), K(H_F8), K(H_F9), K(H_F10), K(H_F11), K(H_F12), M(arduino::KEY_RSHIFT)},
  {M(arduino::KEY_RALT), M(arduino::KEY_RLOGO), M(arduino::KEY_RCTRL), K(H_INS), K(H_LEFT), K(H_DOWN), K(H_UP), K(H_RIGHT)},
  {K(H_SPACE), K(H_DEL), K(H_PGDN), K(H_HOME), K(H_END), K(H_ENTER), K(H_BKSP), K(H_TAB)}
};

const KeyDef (*activeKeymap)[kCols] =
#if defined(HALF_RIGHT)
  kRightKeymap;
#else
  kLeftKeymap;
#endif

Adafruit_MCP23X17 mcp;
arduino::USBKeyboard Keyboard;
bool rawState[kRows][kCols] = {};
bool debouncedState[kRows][kCols] = {};
uint32_t changedAt[kRows][kCols] = {};
uint32_t nextBatteryReportMs = 0;

float readBatteryVoltage() {
  analogReadResolution(12);
  const int raw = analogRead(kBatterySensePin);
  const float sensed = (static_cast<float>(raw) / 4095.0f) * 3.3f;
  return sensed * kBatteryDividerScale;
}

uint8_t batteryPercent(float vbat) {
  float pct = (vbat - kBatteryEmptyV) * 100.0f / (kBatteryFullV - kBatteryEmptyV);
  if (pct < 0.0f) pct = 0.0f;
  if (pct > 100.0f) pct = 100.0f;
  return static_cast<uint8_t>(pct + 0.5f);
}

void setAllRowsHigh() {
  for (uint8_t r = 0; r < kRows; ++r) {
    mcp.digitalWrite(kRowPins[r], HIGH);
  }
}

void sendKeyboardReport() {
  uint8_t modifierMask = 0;
  uint8_t usages[6] = {0, 0, 0, 0, 0, 0};
  uint8_t usageCount = 0;

  for (uint8_t r = 0; r < kRows; ++r) {
    for (uint8_t c = 0; c < kCols; ++c) {
      if (!debouncedState[r][c]) continue;
      const KeyDef key = activeKeymap[r][c];
      modifierMask |= key.modifier;
      if (key.usage != 0 && usageCount < 6) {
        usages[usageCount++] = key.usage;
      }
    }
  }

  HID_REPORT report;
  report.data[0] = 1;
  report.data[1] = modifierMask;
  report.data[2] = 0;
  report.data[3] = usages[0];
  report.data[4] = usages[1];
  report.data[5] = usages[2];
  report.data[6] = usages[3];
  report.data[7] = usages[4];
  report.data[8] = usages[5];
  report.length = 9;

  Keyboard.send(&report);
}

void scanMatrix() {
  const uint32_t now = millis();
  bool changed = false;

  for (uint8_t row = 0; row < kRows; ++row) {
    setAllRowsHigh();
    mcp.digitalWrite(kRowPins[row], LOW);
    delayMicroseconds(50);

    for (uint8_t col = 0; col < kCols; ++col) {
      const bool pressed = (mcp.digitalRead(kColPins[col]) == LOW);

      if (pressed != rawState[row][col]) {
        rawState[row][col] = pressed;
        changedAt[row][col] = now;
      }

      if ((now - changedAt[row][col]) >= kDebounceMs && debouncedState[row][col] != rawState[row][col]) {
        debouncedState[row][col] = rawState[row][col];
        changed = true;
      }
    }
  }
  setAllRowsHigh();

  if (changed) {
    sendKeyboardReport();
  }
}

void reportBatteryIfDue() {
  const uint32_t now = millis();
  if (now < nextBatteryReportMs) return;
  nextBatteryReportMs = now + 30000;

  const float vbat = readBatteryVoltage();
  const uint8_t pct = batteryPercent(vbat);
  Serial.print("Battery: ");
  Serial.print(pct);
  Serial.print("% (");
  Serial.print(vbat, 2);
  Serial.println("V)");
}
}

void setup() {
  Serial.begin(115200);
  delay(150);

  pinMode(kBuzzerPin, OUTPUT);
  digitalWrite(kBuzzerPin, LOW);

  Wire.begin();
  if (!mcp.begin_I2C(kMcpAddress, &Wire)) {
    Serial.println("MCP23017 not found at 0x20.");
    while (true) {
      digitalWrite(kBuzzerPin, HIGH);
      delay(80);
      digitalWrite(kBuzzerPin, LOW);
      delay(920);
    }
  }

  for (uint8_t c = 0; c < kCols; ++c) {
    mcp.pinMode(kColPins[c], INPUT_PULLUP);
  }
  for (uint8_t r = 0; r < kRows; ++r) {
    mcp.pinMode(kRowPins[r], OUTPUT);
  }
  setAllRowsHigh();

  digitalWrite(kBuzzerPin, HIGH);
  delay(40);
  digitalWrite(kBuzzerPin, LOW);

  Serial.println(
#if defined(HALF_RIGHT)
    "SplitKeyboard firmware: RIGHT half"
#else
    "SplitKeyboard firmware: LEFT half"
#endif
  );
}

void loop() {
  scanMatrix();
  reportBatteryIfDue();
  delay(2);
}

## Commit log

2026-03-31 auto sync 2026-03-31 20:03:27
    [Keebright.f3d, Split Keyboard.3mf]
2026-03-31 auto sync 2026-03-31 20:13:27
    [Keebright.f3d]
2026-03-31 Add Hotswap sockets to the materials list
